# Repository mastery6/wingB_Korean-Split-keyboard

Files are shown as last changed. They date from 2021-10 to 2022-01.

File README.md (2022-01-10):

# WingB_Korean-Split-keyboard


|준비물|설명|링크
|-----|-----|-----|
|3D 프린팅 출력 케이스|메이커스페이스➡️|https://www.makeall.com/reservation/map.php|
|아두이노 프로 마이크로 2개|납땜 된거 추천|https://smartstore.naver.com/codingbird/products/4964838948|
|5핀 to USB|집에 하나쯤은 있으시죠..?|
|PJ325(오디오 커넥터) 2개|다른 TRS or TRRS 커넥터 호환가능|https://www.devicemart.co.kr/goods/view?no=2679|
|3.5mm aux 케이블|1m 이상 추천|
|다이오드(1N4148) 64개||https://www.devicemart.co.kr/goods/view?no=25|
|M3 접시머리 머신스크류 10mm (볼트) 14개||https://www.devicemart.co.kr/goods/view?no=34782|
|M3 인서트 너트 14개||https://www.devicemart.co.kr/goods/view?no=1067969|
|하네스 케이블 10핀 or 12핀 4개|위쪽 두개는 사용하지 않아 10핀도 가능합니다|https://www.devicemart.co.kr/goods/view?no=10894393|
|스위치 64개|게이트론, 카일, 체리 등등|
|키캡 64개|DSA 무각 104키 추천|
|카일 핫스왑 소켓 64개 (선택)|핫스왑 하실 분들만|
|전선|랩핑와이어 추천(인두기로 녹여서 사용가능)|https://www.devicemart.co.kr/goods/view?no=1274107|
|납땜 재료|인두기, 납, 인두기 스탠드 등등|
|글루건 or 본드|
|미끄럼 방지 패드 or 범퍼|저는 10파이 제품 사용했습니다|https://smartstore.naver.com/mg9000/products/3289975643|

재료는 디바이스마트나 엘레파츠에서 구매가능합니다

## 1. 3D프린터로 케이스 출력

## 2. 케이스 서포트 제거
스크린샷 2021-10-04 오전 12 17 17
(서포트 - 빨간색)

## 3. 납땜

행 부분에서는 스위치에 다이오드를 연결해주고 다이오드의 검정부분을 연결

## 4. Pro micro - 스위치, TRRS 연결

스크린샷 2021-10-03 오후 11 45 57
스크린샷 2021-10-03 오후 11 45 57
스크린샷 2021-10-03 오후 11 46 15
스크린샷 2021-10-03 오후 11 46 15
스크린샷 2021-10-03 오후 11 46 15

## 5. 키맵핑

QMK 키코드
https://beta.docs.qmk.fm/using-qmk/simple-keycodes/keycodes
스크린샷 2021-10-03 오후 11 46 15
스크린샷 2021-10-03 오후 11 46 15
    
    qmk compile -kb wingB -km default

## 6. Flash (아두이노에 코드 업로드)
QMK Toolbox
https://github.com/qmk/qmk_toolbox/releases
스크린샷 2021-10-03 오후 11 48 50

아두이노 RST, GND 연결
노란색 Connect표시가 뜨면 Flash 클릭

## ETC
104키 키보드 키캡 사이즈 


star 한번씩 눌러주시면 감사드리겠습니다..ㅎ

## 수정사항
21.01.10 hexfile Trrs 2번에서 3번으로 수정

## 상업적 이용 금지합니다!

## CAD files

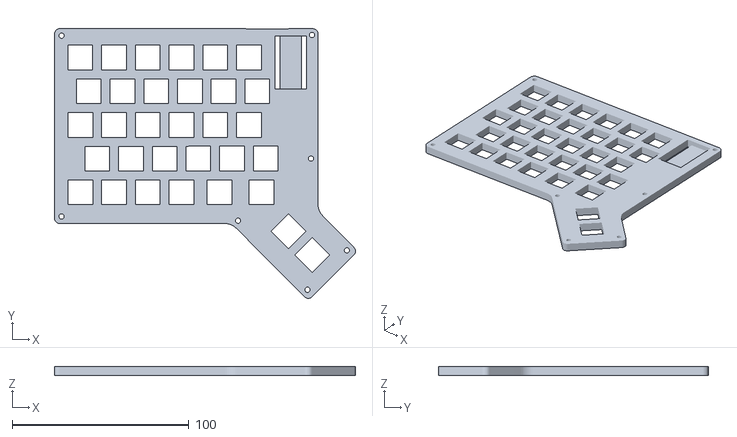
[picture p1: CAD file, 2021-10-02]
stl/right_top.stl
170.1 x 152.5 x 5.00

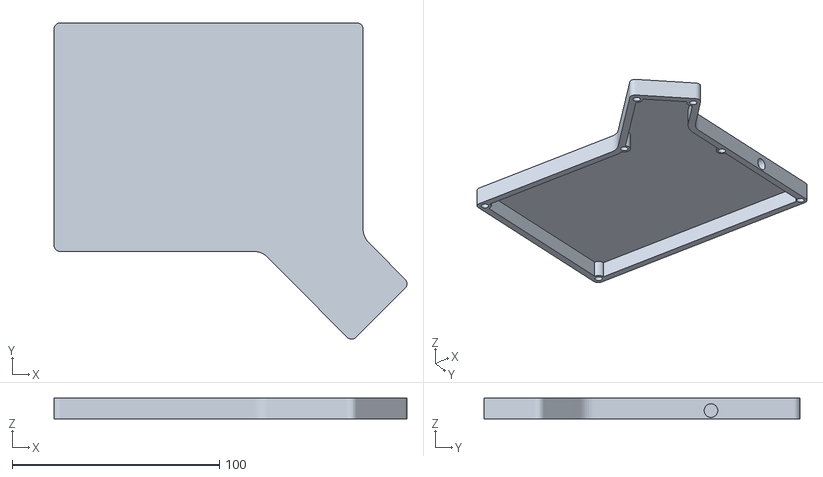
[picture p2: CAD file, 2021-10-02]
stl/right_bottom.stl
170.1 x 152.5 x 10.0

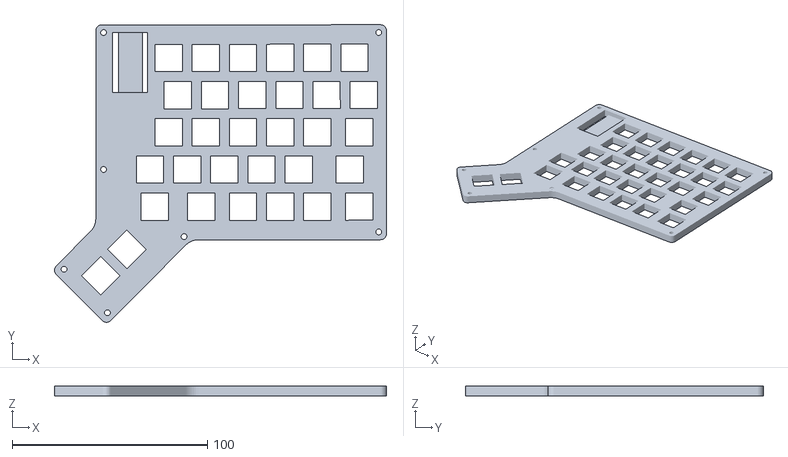
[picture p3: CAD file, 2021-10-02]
stl/left_top.stl
170.1 x 152.5 x 5.00

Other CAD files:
stl/left_bot.stl

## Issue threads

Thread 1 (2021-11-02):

정말 감사합니다!!

Dev-JiwonShin, 2021-11-02:
대학생개발자입니다. 업무 최적화에 재미들리다보니 이제는 키보드 뜯는 것도 즐기게 되었습니다 ㅎㅎ

스플릿 키보드를 블랙프라이데이 맞춰서 lily58로 구매할까,,하던 찰나에 유튜브 영상 통해 이 키보드를 보게 되었네요!!

시험 끝나는대로 이 프로젝트에 필요한 부품들을 하나씩 주문해서 만들어볼 생각입니다 !!

제가 컴공과라서 회로 기판이나 전선연결 납땜질 등을 하나도 모르는데, 혹시 어디서 어떻게 배울 수 있는지 알고싶습니다!

이 키보드 만드는데 필요한 지식을 얻을만한, 추천하는 유튜브나 블로그 링크가 있으실까요??

이런 프로젝트를 진행해주셔서 다시 한 번 감사드립니다 ㅎㅎ 스타도 눌렀습니다!

kimsr96, 2021-11-05:
안녕하세요. 처음부터 전부 배우기보다는 부분부분 필요한 것만 배워도 될 거 같아요.
예를 들면 유튜브에 납땜 하는 법 이런식으로,, 어려운거는 없습니다..!
북마크 해둔 링크가
https://github.com/diimdeep/awesome-split-keyboards
https://golem.hu/
키보드매니아
쿨앤조이
클리앙
이 정도 있습니다..!
저도 필요한 부분만 구글링하거나 유튜브 검색하면서 배워서,, 튜토리얼이나 그런게 마땅치 않네요 ㅠ

Dev-JiwonShin, 2021-11-14:
답변 감사합니다! 사진, 유튜브 영상 보면 아두이노칩은 보호덮개? 없이 외부로 노출된 상태인데, 그렇게 써도 무방한가요?? 릴리58키보드도 거의 비슷한데 아크릴 같은 실드로 덮여있어서 여쭤봅니다!

kimsr96, 2021-11-15:
납땜이 되있는 상태고 외부 충격이 가해지는 상황이 없다면 상관없어요~ 혹시 키보드를 가방에 넣거나 휴대할 때에는 5핀 케이블선만 빼서 휴대해주세요
저도 처음에는 아두이노를 케이스 안으로 넣으려고 했는데 그러면 키보드가 높아져서 외부로 노출시켰습니다.. 만들어보니 다 이유가 있더라구요ㅎㅎ;

Dev-JiwonShin, 2021-11-15:
역시 다 이유가 있군요 ㅎㅎ,, 납땜 되어있는 아두이노 칩을 pcb에 꽂은 후 납땜 처리를 한 번 더 해주어야 하나요..?

mastery6, 2021-11-15:
아니요~

Dev-JiwonShin, 2021-11-15:
답변 감사합니다,,! 용기 얻어서 도전해볼게요!
